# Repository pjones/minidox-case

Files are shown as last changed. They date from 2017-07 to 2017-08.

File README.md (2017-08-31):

# Minidox Case

A 3D-printed case for the [Minidox][].

## What You Should Print

Each half will need a case and a top.  If you want to print the cover
too, make sure you print the case that has the cover option.

# What to Expect

After getting everything put together you will probably need to trim
some of the key cap openings on the top plate.

Regrettably, I designed the case to have a little bit of wiggle room
to make inserting the PCB easier.  But this means the PCB and top
plate may not align correctly.

## Pictures

all done

case with cover shelf

More pictures: http://imgur.com/a/ioUCZ

[minidox]: https://geekhack.org/index.php?topic=89951.0

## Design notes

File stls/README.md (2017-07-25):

# Generated STL Files

**WARNING:** These files are automatically generated.  Do not edit
them.  Edit the `../minidox-case.scad` file instead.

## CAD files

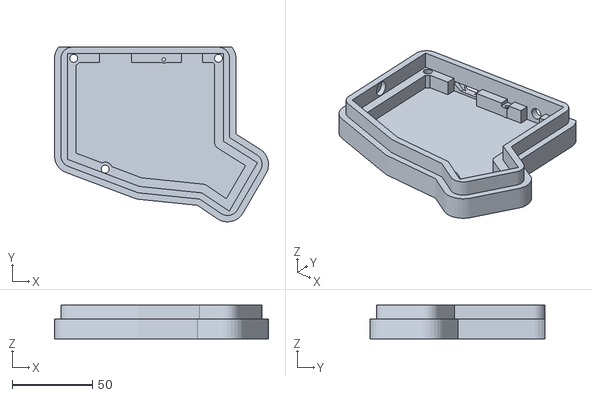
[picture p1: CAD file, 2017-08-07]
stls/case/case-left-with-cover.stl
133.5 x 109.1 x 21.0

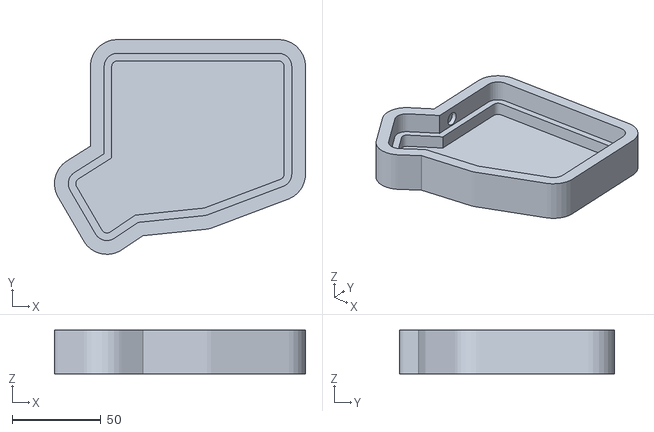
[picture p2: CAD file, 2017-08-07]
stls/cover/cover-left.stl
141.5 x 121.1 x 24.8

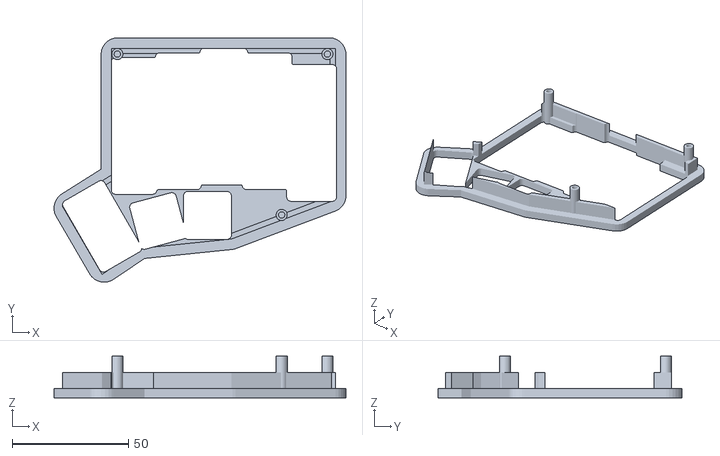
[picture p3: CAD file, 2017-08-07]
stls/top/top-left.stl
125.5 x 105.1 x 18.0

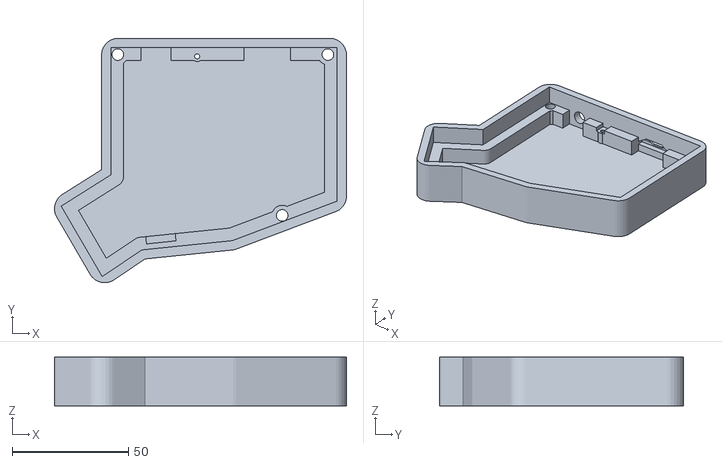
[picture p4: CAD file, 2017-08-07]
stls/case/case-right.stl
125.5 x 105.1 x 21.0

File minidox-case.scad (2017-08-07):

/******************************************************************************/
/*
  This file is part of the package minidox-case. It is subject to the
  license terms in the LICENSE file found in the top-level directory
  of this distribution and at:

    https://github.com/pjones/helping-mic

  No part of this package, including this file, may be copied, modified,
  propagated, or distributed except according to the terms contained in
  the LICENSE file.
*/

/******************************************************************************/
$fa = 1.0;
$fs = 0.5;

/******************************************************************************/
/*
  Note: All of the measurements in this file are for the RIGHT side.
  To generate the left side the model is mirrored in the X axis.
*/

/******************************************************************************/
// These are set from the command line:
print_side = "right";           /* right or left */
print_part = "case";            /* case, top, or cover */

/******************************************************************************/
// Optional features:
feature_cover = false;           /* Will you use a cover? */
feature_magnets = false;         /* Add holes to hold magnets? */

/******************************************************************************/
// Settings you may want to tweak:
inner_depth = 9.0;              /* How high the case will come up from the board upward. */
inner_spacing = 2.25;           /* Space under the board to hold it. */
outer_spacing = 1.0;            /* Extra space in the case for the board to fit in. */
cover_inner_space = 0.0;        /* Extra space in the cover for cables, etc. */
board_thickness = 1.6;          /* Thickness of circuit board. */
switch_height = 11.75;          /* Space between top of board and bottom of key cap */
cap_height = 7.90;              /* Height of keycap. */
bolt_size = [3.0, 16.0];        /* M3x16 */
bolt_inset = 2.5;               /* From wall to center of bolt. */
bolt_shaft_wall = 2.0;          /* Wall thickness of shaft bolt screws into. */
bolt_recess = 2.0;              /* How deep bolts go into the bottom. */

/******************************************************************************/
// If using magnets to hold the cover on, fill these out and add a
// small amount of extra so the magnet can go in easily.
//
// The exact measurements of the magnets I'm using are:
//   7.95mm x 2.80mm;
magnet_diameter = 8.25;         /* Magnet diameter. */
magnet_depth = 3.00;            /* Magnet depth. */

/******************************************************************************/
// I don't recommend changing these:
rounding = 2.25;                /* How much rounding to apply. */
thickness = 4;                  /* Wall thickness. */
board_overlap = 1.8;            /* Space around the board the top can sit on */

/******************************************************************************/
// Points that outline the desired case shape:
outline = [
  [0.00,     0.00],
  [95.30,    0.00],
  [95.30,  -64.30],
  [51.00,  -81.00],
  [12.00,  -85.00],
  [-4.40,  -96.00],
  [-21.00, -67.50],
  [0.00,   -54.25],
];

/******************************************************************************/
// Points that outline the shape to cut out of the top so the key caps
// can poke through:
cap_1U = [18.25, 18.25, 0.85, 0.85];
cap_2U = [cap_1U[0], 32.75, 0.85, 0.85];

rows = 3;
columns = 5;

function cap_over(keys) =
  /* Size of keycaps + Size of space between them */
  (cap_1U[0] * keys) + (cap_1U[2] * keys);

function cap_back(keys) =
  cap_over(columns) - (cap_over(keys - 1) + (keys == 1 ? 0 : cap_1U[2]));

function column_over(column, base) = lookup(column, [
    [ 1, -4.00 ],
    [ 2, -2.00 ],
    [ 3, -0.00 ],
    [ 4, -2.00 ],
    [ 5, -7.00 ],
  ]) + base;

// Position the entire cut out by placing the center of column in the
// center of the inner case.
cap_x_mid = max([for (i = outline) i[0] + outer_spacing])/2;
cap_x_start = cap_x_mid - (cap_over(3) - cap_1U[0]/2 - cap_1U[2]/2) - 0.25;

cap_y_upper = -0.25;
cap_y_lower = cap_y_upper + -(cap_1U[1] * rows + cap_1U[3] * rows);

top_cut = [
  // Upper half:
  [cap_x_start, column_over(1, cap_y_upper)], // Left of Y
  [cap_over(1), column_over(1, cap_y_upper)], // Left of U
  [cap_over(1), column_over(2, cap_y_upper)], // Left of U (moved up)
  [cap_over(2), column_over(2, cap_y_upper)], // Left of I
  [cap_over(2), column_over(3, cap_y_upper)], // Left of I (moved up)
  [cap_over(3), column_over(3, cap_y_upper)], // Left of O
  [cap_over(3), column_over(4, cap_y_upper)], // Left of O (moved down)
  [cap_over(4), column_over(4, cap_y_upper)], // Left of P
  [cap_over(4), column_over(5, cap_y_upper)], // Left of P (moved down)
  [cap_over(5), column_over(5, cap_y_upper)], // Right of P

  // Lower half:
  [cap_back(1), column_over(5, cap_y_lower)], // Right of /
  [cap_back(2), column_over(5, cap_y_lower)], // Left of /
  [cap_back(2), column_over(4, cap_y_lower)], // Left of / (moved up)
  [cap_back(3), column_over(4, cap_y_lower)], // Left of .
  [cap_back(3), column_over(3, cap_y_lower)], // Left of . (moved up)
  [cap_back(4), column_over(3, cap_y_lower)], // Right of M
  [cap_back(4), column_over(2, cap_y_lower)], // Right of M (moved down)
  [cap_back(5), column_over(2, cap_y_lower)], // Right of N
  [cap_back(5), column_over(1, cap_y_lower)], // Right of N (moved down)
  [cap_x_start, column_over(1, cap_y_lower)], // Left of N
];

// Now the three thumb keys:
thumb_3 = [ cap_x_mid - 7.40  // x offset (center of cap)
          , 71.35             // y offset (center of cap)
          , 0.00              // rotation (counterclockwise)
          ];

thumb_2 = [ thumb_3[0] - 21.25
          , thumb_3[1] + 2.40
          , 15.00
          ];

thumb_1 = [ thumb_2[0] - 24.00
          , thumb_2[1] + 2.30
          , 30.0
          ];

/******************************************************************************/
// Size of the pro micro body and TRRS jack.
//
// Elements:
//  - x size
//  - y size
//  - z size
//  - x offset to center of device
//  - z offset to center of device's opening measured from the bottom
//    of the circuit board to the center of the opening.
//
pro_micro = [ 20.0
            , 34.0
            , 6.0 // Used to set the inner height of the case.
            , 66.75
            , print_side == "right" ? 1.3 : 4.5
            ];

trrs = [ 13.0
       , 13.0
       , 5.23
       , 18.90
       , 2.16
       ];

/******************************************************************************/
// Other computed values:
board_to_caps = switch_height + cap_height;
wall_thickness_no_padding = feature_cover ? thickness * 2 : thickness;
wall_thickness = wall_thickness_no_padding + outer_spacing/2;
bolt_shaft = bolt_size[0] + bolt_shaft_wall;
shelf_width = inner_spacing + outer_spacing + rounding;

/******************************************************************************/
reset_button = [ 5.2            /* x */
               , shelf_width    /* y */
               , 2              /* z */
               , 36.6           /* center of x */
               , 3.25           /* center of y */
               , 2.25           /* diameter of reset hole */
               ];

/******************************************************************************/
// How high to make the shelf that the board sits on:
inner_height = pro_micro[2] + 2.0;
echo("INNER HEIGHT: ", inner_height);

/******************************************************************************/
// Full case height:
outer_height = inner_height + inner_depth;
echo("OUTER HEIGHT:", outer_height);

/******************************************************************************/
// How big the cover needs to be to enclose everything:
cover_inner_height =
  board_to_caps + board_thickness + // Everything from the shelf upwards
  thickness +                       // To include the top wall of the cover
  cover_inner_space -               // And extra space
  (inner_depth + thickness);        // Remove space used by case and top

echo("COVER INNER HEIGHT:", cover_inner_height);

/******************************************************************************/
// How big is the cover on the outside:
cover_outer_height = cover_inner_height + thickness + outer_height/2;
echo("COVER OUTER HEIGHT:", cover_outer_height);

/******************************************************************************/
case_width = max([ for (i = outline) i[0] ]) +
  ((outer_spacing + thickness)*2) +
  (feature_cover ? thickness*2 : 0);

case_y_width = min([ for (i = outline) i[1] ]) * -1;

cover_wall_height = outer_height/2 + thickness;
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

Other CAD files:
stls/cover/cover-right.stl
stls/top/top-right.stl
stls/case/case-left.stl
stls/case/case-right-with-cover.stl

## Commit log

2017-07-15 Initial import
    [minidox-case.scad]
2017-07-16 Fix bad locations and printing artifacts
    * The location of the TRRS jack was too far to the left
    * The cutout for the pro micro board printed terribly
    * Added material for the reset hole so it's not exposed
    [minidox-case.scad]
2017-07-19 First attempt at a top for the case
    [minidox-case.scad]
2017-07-20 Tweaks to the top cutout
    [minidox-case.scad]
2017-07-20 Improve the case so I can work more on the top
    [minidox-case.scad]
2017-07-20 Small cap cutout adjustments, first attempt at thumb cutouts
    [minidox-case.scad]
2017-07-20 Tweak thumb key locations
    [minidox-case.scad]
2017-07-21 Completely rework the key caps so they are in relation to one another
    [minidox-case.scad]
2017-07-21 The top plate is pretty good with these numbers
    [minidox-case.scad]
2017-07-21 Revert a few case changes, ready to print a final top
    [minidox-case.scad]
2017-07-21 First attempt at building a case intended for a cover with magnet holes
    [minidox-case.scad]
2017-07-22 Make top studs a bit stronger
    [minidox-case.scad]
2017-07-22 Small tweaks to the thumb keys and the Y padding on 1U keys
    [minidox-case.scad]
2017-07-22 Fix stud holes, and thumb key 3
    This better be the last damn thumb key adjustment.
    [minidox-case.scad]
2017-07-23 Improve the USB cutout hole
    [minidox-case.scad]
2017-07-24 First version of the cover
    [minidox-case.scad]
2017-07-24 Restore part settings to default, tweak USB opening
    [minidox-case.scad]
2017-07-25 Revert back to a smaller amount of spacing inside the case
    I thought having some extra space to fit the board into the case was a
    good idea. It turns out, once you put the top on the case the board
    is forced into the center of the case and you can't plug anything into
    the rear of the case.
    [minidox-case.scad]
2017-07-25 Increase the thickness of the thin inner pieces left after cutting out the key caps
    [minidox-case.scad]
2017-07-25 Add README and STL files
    [case-left-with-cover.stl, case-left.stl, case-right-with-cover.stl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]
2017-07-25 Put the magnet holes in a predictable location
    This change makes it so both the case and cover will have the magnet
    holes in locations that correctly line up.
    [case-left-with-cover.stl, case-left.stl, case-right-with-cover.stl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]
2017-07-27 New implementation of thumb keys, starting final prints
    [case-left-with-cover.stl, case-left.stl, case-right-with-cover.stl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]
2017-07-27 Small movement for the 2U thumb key
    Hopefully this will be universal because I was having trouble with the
    top fitting on the left case.
    [case-left-with-cover.stl, case-left.stl, case-right-with-cover.stl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]
2017-07-27 Correction to cover height which results in a smaller cover
    [case-left-with-cover.stl, case-left.stl, case-right-with-cover.stl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]
2017-07-28 Include the upper wall thickness in the cover height calculation
    [minidox-case.scad]
2017-07-29 Continued adjustments to the top cutouts for the thumb keys
    [case-left-with-cover.stl, case-left.stl, case-right-with-cover.stl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]
2017-08-07 Add some feet for the cover, add some bad pictures to the README
    [case-left-with-cover.stl, case-left.stl, case-right-with-cover.stl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]
